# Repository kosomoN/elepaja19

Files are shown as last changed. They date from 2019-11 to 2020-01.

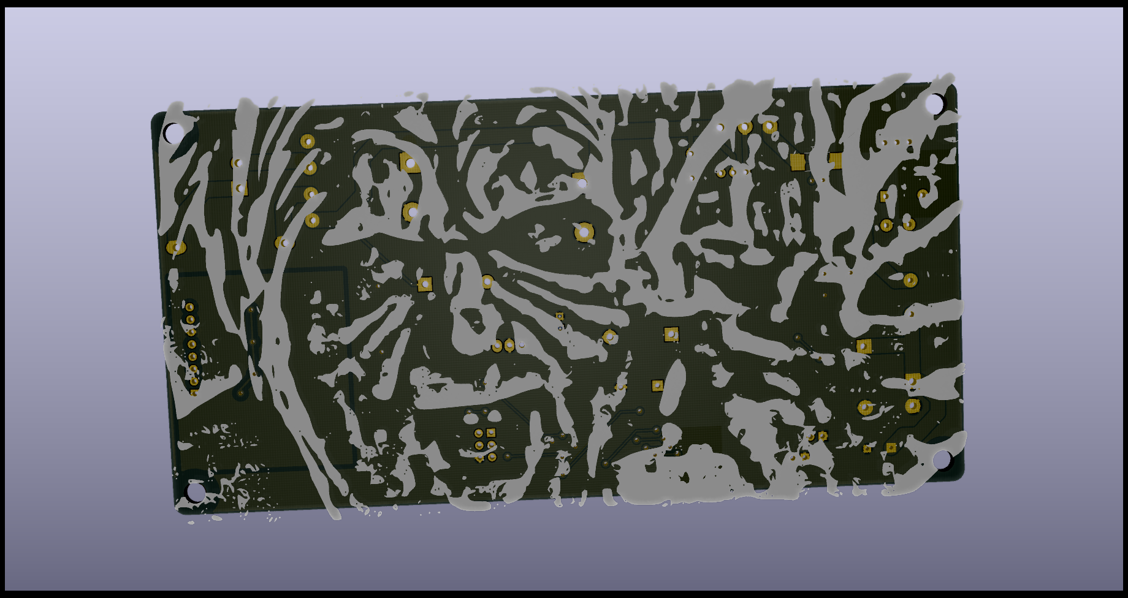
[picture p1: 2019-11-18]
pcb_1/pcb_1.png

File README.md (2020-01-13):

## Lab power supply

This repository contains firmware and PCB designs for a lab power supply designed by Onni Kosomaa, Jere Mielty and Juha Rauhala.

### Repository contents

| Folder | Contents |
| --- | --- |
| [components](components) | Custom KiCad component used in the schematics. |
| [control_mc](control_mc) | The regulator MCU firmware. |
| [pcb_1](pcb_1) | The main regulator PCB KiCad project. |
| [pcb_PiHat](pcb_PiHat) | The Raspberry Pi Zero extension PCB KiCad project. |
| [pcb_fpanel](pcb_fpanel) | The main front panel keyboard PCB. |
| [pcb_fpanel2](pcb_fpanel2) | The auxiliary front panel keyboard PCB. |
| [ui](ui) | UI software running on the Raspberry Pi. |

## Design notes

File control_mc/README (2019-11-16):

Dependencies:
    - avr-gcc and avr-libc
    - Atmel pack with ATMEGA328PB files. Looks for them by default in
     ../../packs/gcc/dev/atmega328pb/ and ../../packs/include/
     The pack can be found here: http://packs.download.atmel.com/
                                 (Atmel ATmega Series Device Support (1.4.331))

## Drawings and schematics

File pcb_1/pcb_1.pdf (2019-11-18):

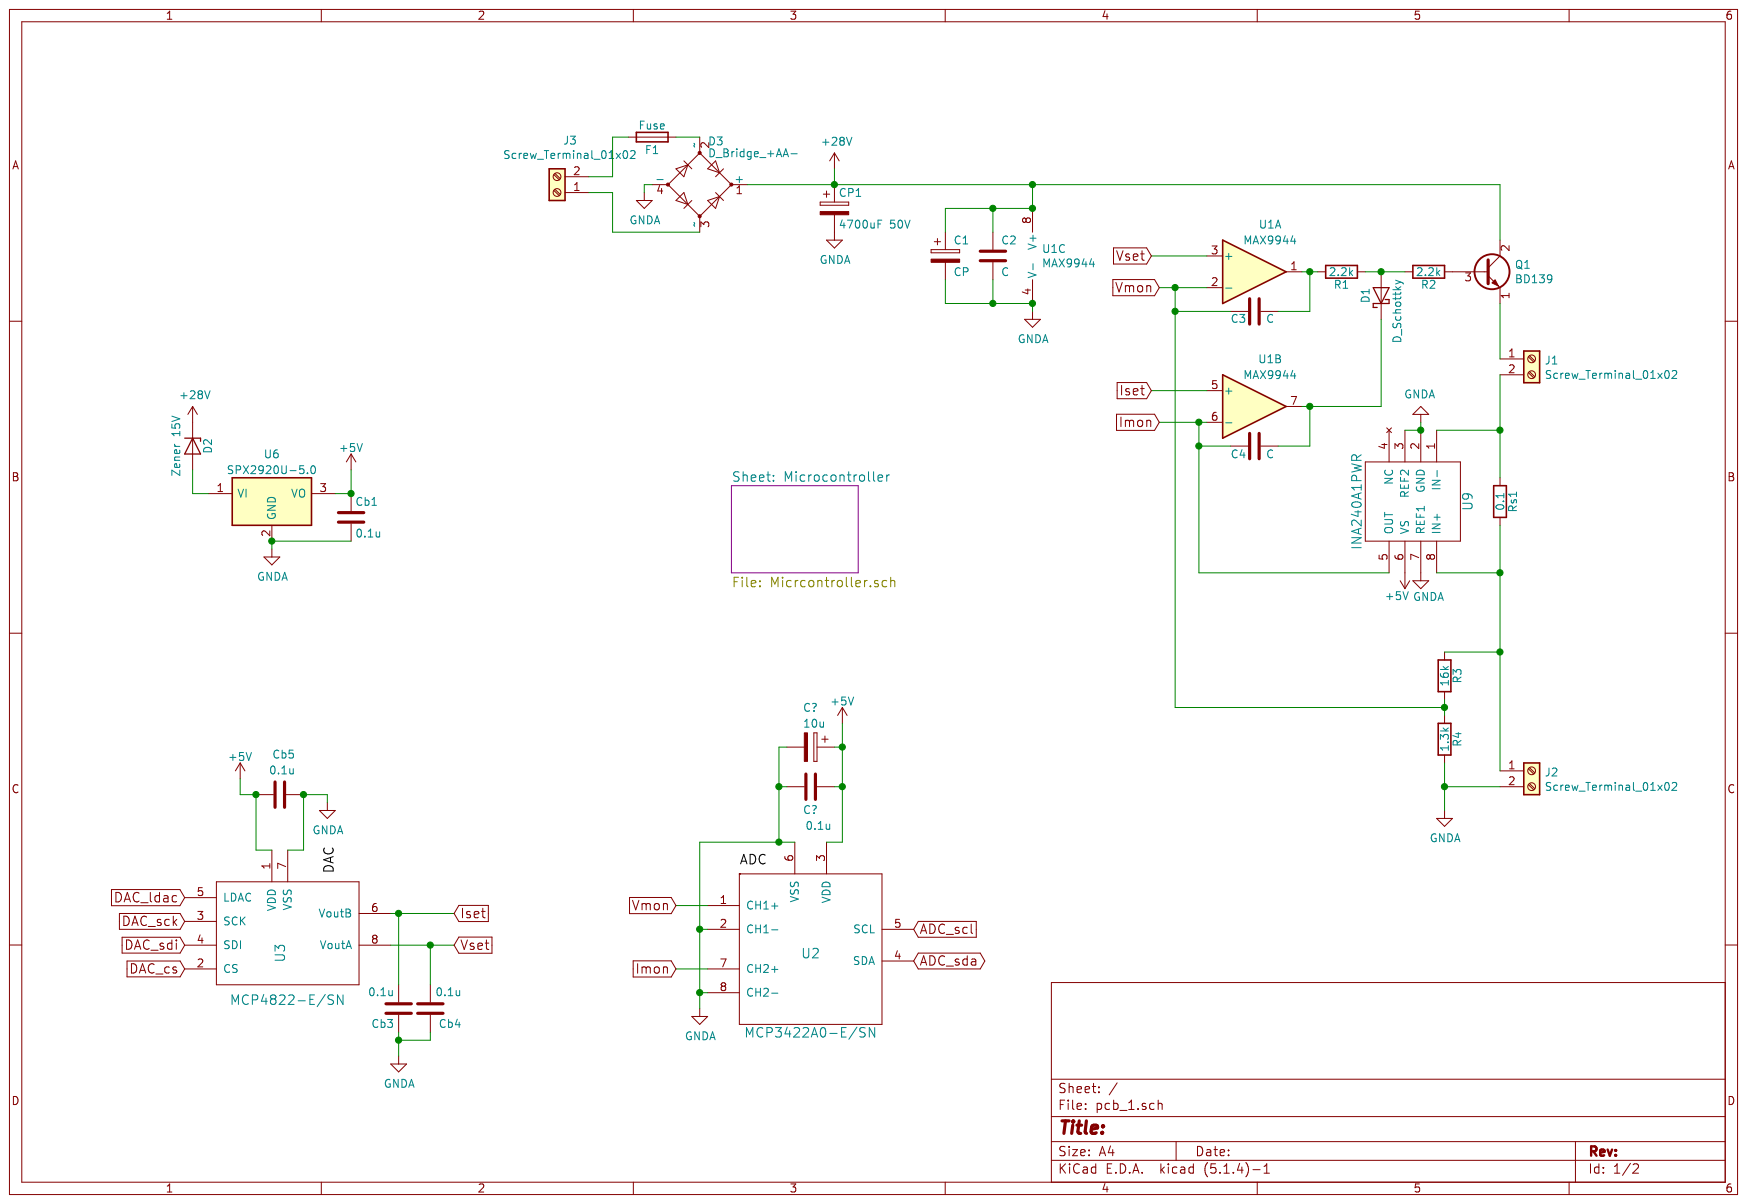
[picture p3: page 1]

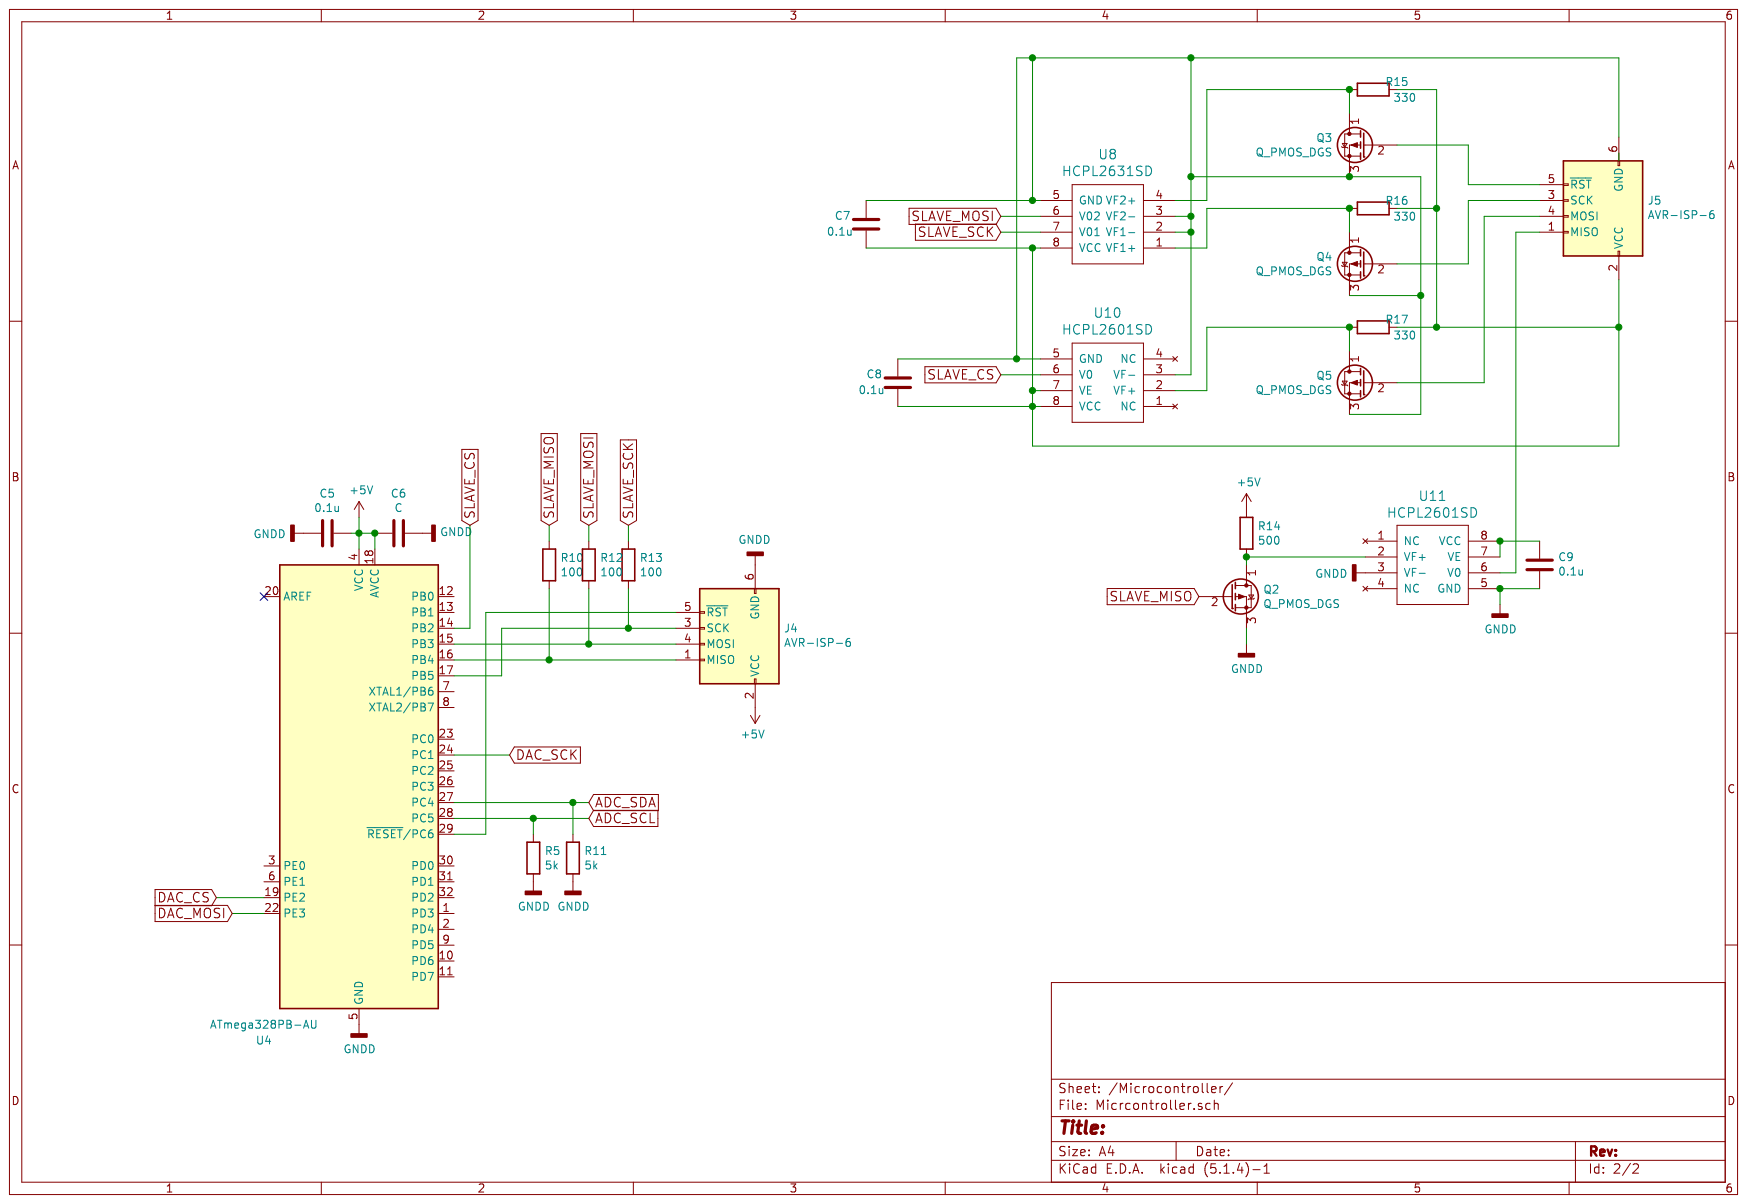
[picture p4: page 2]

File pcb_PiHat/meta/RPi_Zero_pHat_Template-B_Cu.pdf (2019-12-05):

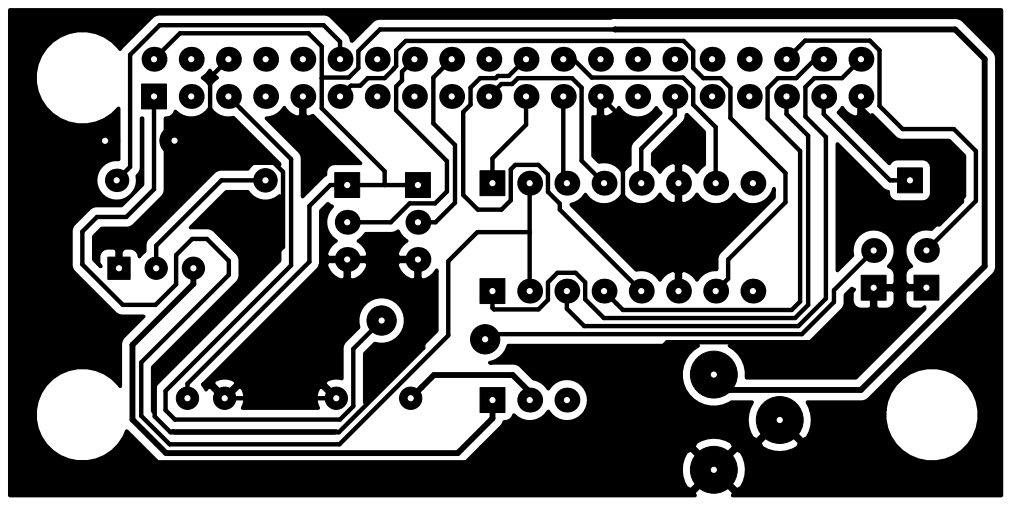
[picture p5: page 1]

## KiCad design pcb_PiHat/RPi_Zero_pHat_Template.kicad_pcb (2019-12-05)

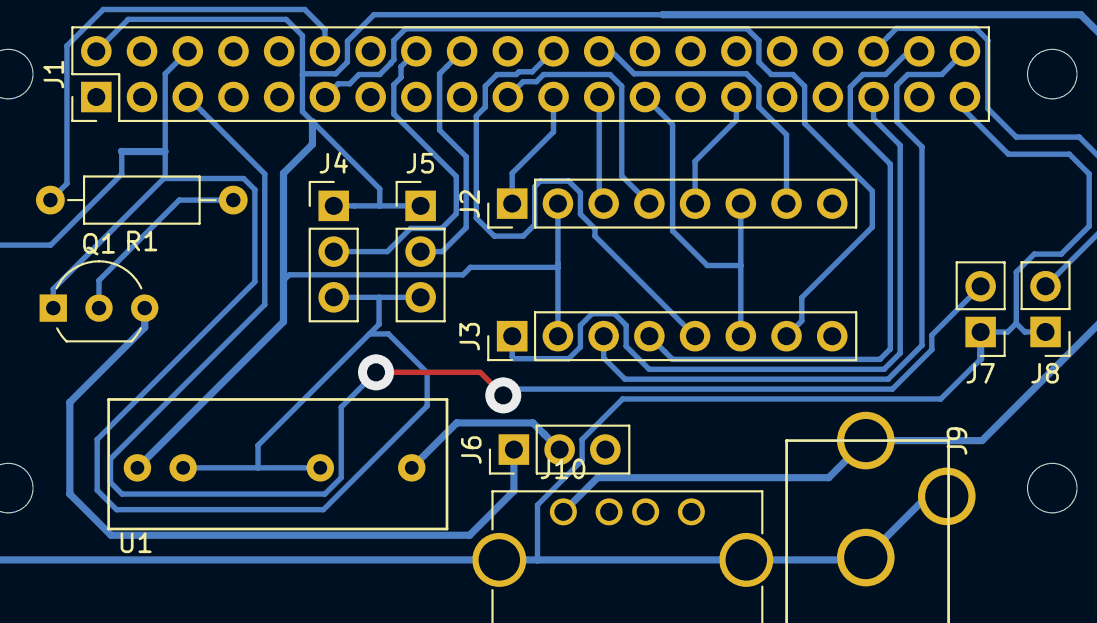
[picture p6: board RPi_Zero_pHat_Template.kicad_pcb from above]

Board: 2 copper layers, 13 parts (0 on the bottom side), 20 nets.

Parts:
J1: RPi_GPIO; PinHeader_2x20_P2.54mm_Vertical
J2, J3: Isolated_ISP; PinHeader_1x08_P2.54mm_Vertical
J4, J5: Conn_Relay; PinHeader_1x03_P2.54mm_Vertical
J6: Conn_01x03; Pin_Header_Straight_1x03_Pitch2.54mm
J7, J8: Conn_switch; Pin_Header_Straight_1x02_Pitch2.54mm
J9: 5V_in; 5V_power
J10: USB_A
Q1: Q_NPN_EBC; TO-92_Inline_Wide
R1: R; R_Axial_DIN0207_L6.3mm_D2.5mm_P10.16mm_Horizontal
U1: SPUN02L-12

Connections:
GND: J1.6, J1.9, J1.14, J1.20, J1.25, J1.30, J1.34, J1.39, J2.6, J3.6, J4.3, J5.3, J7.1, J8.1, J9.2, J10.4, J10.5, Q1.1, U1.2, U1.5
unnamed: J1.2, J2.2, J3.2, J4.1, J5.1, J9.1, J10.1, U1.1
unnamed: J1.5, J7.2
unnamed: J1.11, J3.7
unnamed: J1.12, R1.2
unnamed: J1.16, J4.2
unnamed: J1.18, J5.2
unnamed: J1.19, J2.4
unnamed: J1.21, J2.1
unnamed: J1.22, J3.5
unnamed: J1.23, J2.3
unnamed: J1.24, J2.7
unnamed: J1.29, J2.5
unnamed: J1.35, J3.1
unnamed: J1.36, J8.2
unnamed: J1.38, J3.4
unnamed: J1.40, J3.3
unnamed: J6.1, Q1.3
unnamed: J6.2, U1.7
unnamed: Q1.2, R1.1

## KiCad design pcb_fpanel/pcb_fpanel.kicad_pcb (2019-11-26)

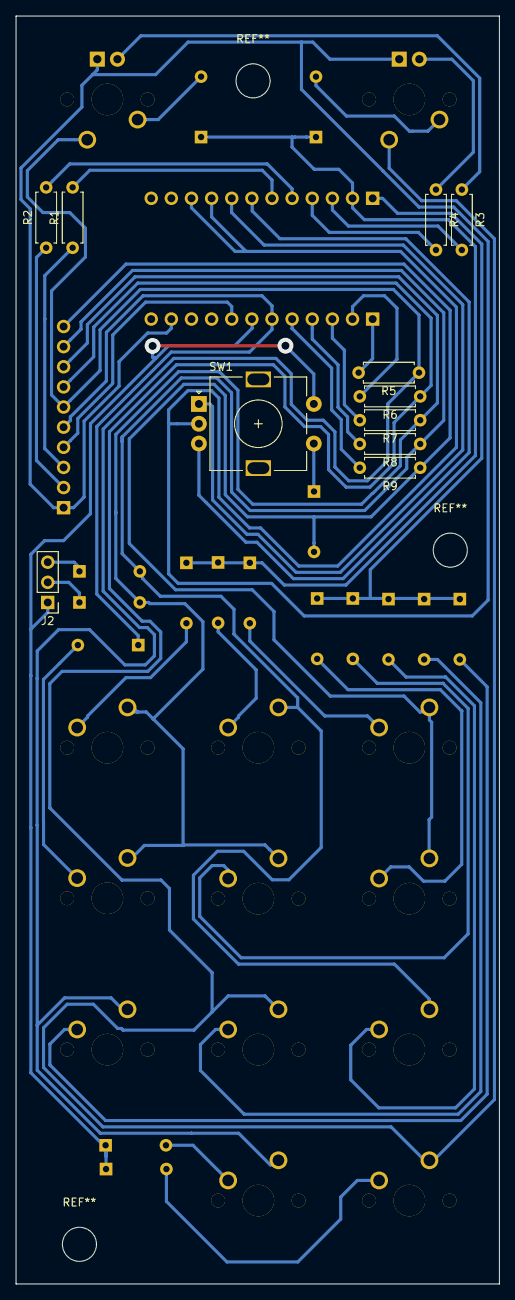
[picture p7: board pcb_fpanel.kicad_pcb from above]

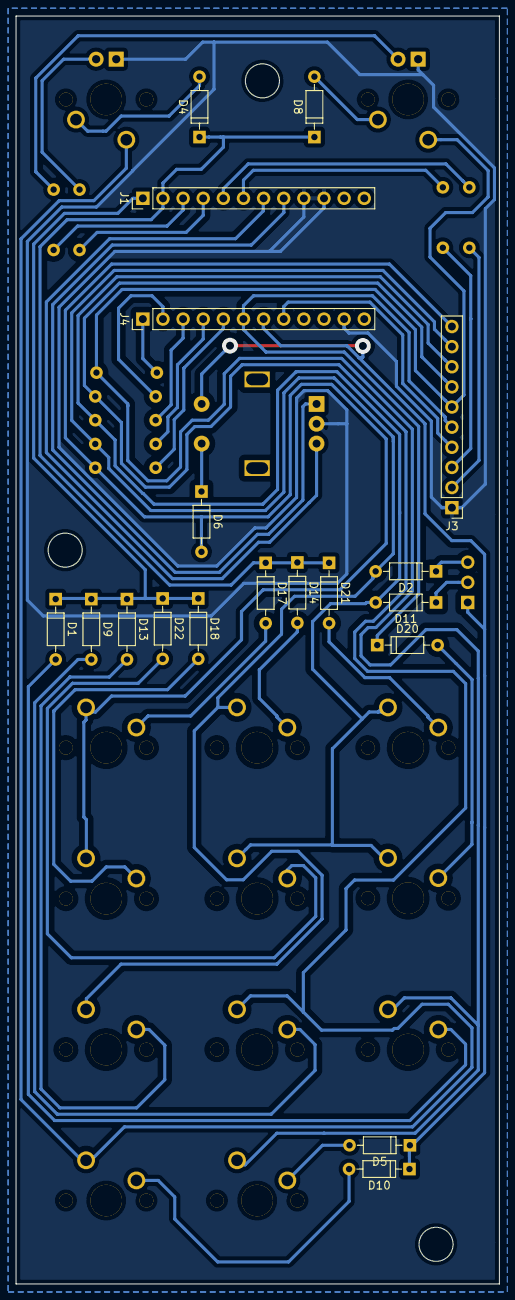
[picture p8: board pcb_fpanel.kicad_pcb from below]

Board: 2 copper layers, 61.0 x 160.0 mm, 43 parts (19 on the bottom side), 40 nets.

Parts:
D1, D2, D4, D5, D6, D8, D9, D10, D11, D13, D14, D17, D18, D20, D21, D22: D; D_DO-35_SOD27_P7.62mm_Horizontal
J1, J4: Conn_01x12; Pin_Header_Straight_1x12_Pitch2.54mm
J2: Conn_01x03; Pin_Header_Straight_1x03_Pitch2.54mm
J3: Conn_01x10; Pin_Header_Straight_1x10_Pitch2.54mm
R1, R2, R3, R4, R5, R6, R7, R8, R9: R; R_Axial_DIN0207_L6.3mm_D2.5mm_P7.62mm_Horizontal
SW1: Rotary_Encoder_Switch; RotaryEncoder_Alps_EC11E-Switch_Vertical_H20mm
SW3, SW8: SW_Push_LED; MXOnly-1U
SW4, SW5, SW9, SW10, SW13, SW14, SW17, SW18, SW20, SW21, SW22: SW_Push_LED; MXOnly-1U-NoLED

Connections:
GNDD: J1.9, J1.10, J3.1, J4.11, SW1.C
unnamed: D1.2, SW4.1
unnamed: D2.1, J2.3
unnamed: D4.2, SW3.1
unnamed: D5.2, SW5.1
unnamed: D8.2, SW8.1
unnamed: D9.2, SW9.1
unnamed: D10.2, SW10.1
unnamed: D11.1, J2.2
unnamed: D13.2, SW14.1
unnamed: D14.2, SW13.1
unnamed: D17.2, SW17.1
unnamed: D18.2, SW18.1
unnamed: D20.2, SW20.1
unnamed: D21.2, SW21.1
unnamed: D22.2, SW22.1
unnamed: J1.3, R3.2
unnamed: J1.4, R4.2
unnamed: J1.5, R2.2
unnamed: J1.6, R1.2
unnamed: J1.7, SW1.B
unnamed: J1.8, SW1.A
unnamed: J4.1, R5.2
unnamed: J4.2, R6.2
unnamed: J4.3, R7.2
unnamed: J4.4, R8.2
unnamed: J4.5, R9.2
column_1: J3.6, R5.1, SW4.2, SW5.2, SW8.2
column_2: J3.7, R6.1, SW3.2, SW9.2, SW10.2
column_3: D2.2, J3.9, R8.1, SW13.2, SW14.2
column_4: D6.2, J3.10, R9.1, SW17.2, SW18.2
column_5: D11.2, J3.8, R7.1, SW20.2, SW21.2, SW22.2
encoder_button: D6.1, SW1.S1
led_1: J3.3, R1.1
led_2: J3.2, R2.1
row_1: J3.4, J4.8
row_2: D20.1, J3.5, J4.6
row_3: D4.1, D8.1, D14.1, D17.1, D21.1, J1.2
row_4: D1.1, D9.1, D13.1, D18.1, D22.1, J1.1
row_5: D5.1, D10.1, J2.1, J4.7, SW1.S2

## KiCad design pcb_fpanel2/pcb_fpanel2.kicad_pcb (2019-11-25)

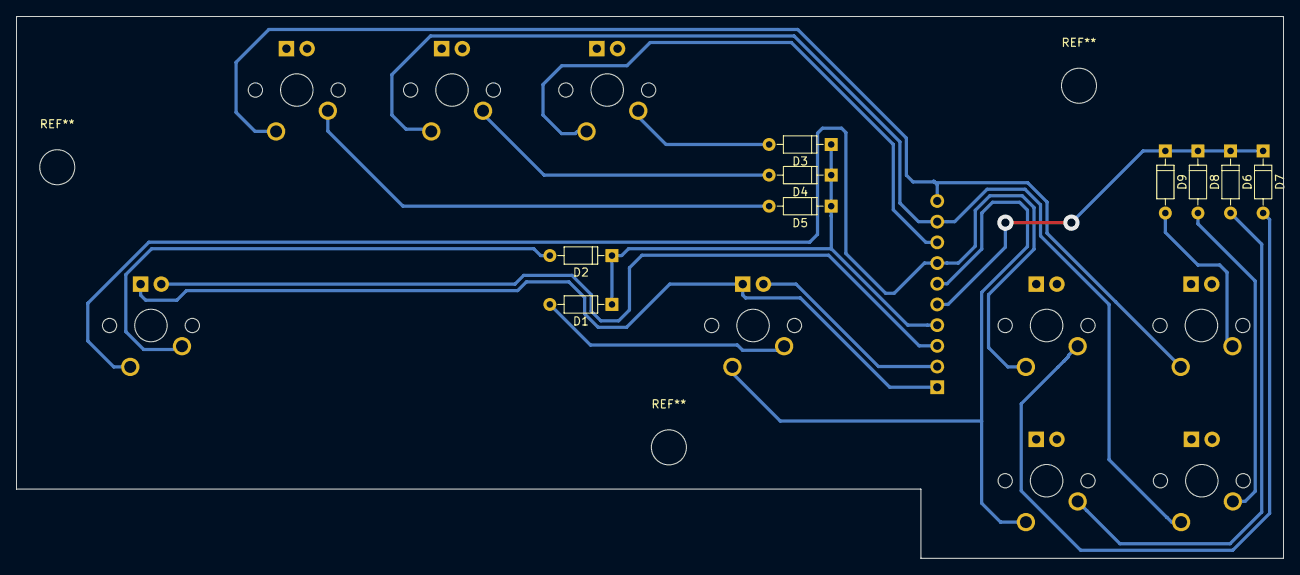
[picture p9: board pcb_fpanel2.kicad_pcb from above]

Board: 2 copper layers, 155.5 x 66.5 mm, 19 parts (1 on the bottom side), 19 nets.

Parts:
D1, D2, D3, D4, D5, D6, D7, D8, D9: D; D_DO-35_SOD27_P7.62mm_Horizontal
J1: Conn_01x10; Pin_Header_Straight_1x10_Pitch2.54mm
SW1, SW2, SW3, SW4, SW5, SW6, SW7, SW8, SW9: SW_Push_LED; MXOnly-1U

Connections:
GNDD: J1.1, SW1.4, SW2.4
unnamed: D1.2, SW1.1
unnamed: D2.2, SW2.1
unnamed: D3.2, SW3.1
unnamed: D4.2, SW4.1
unnamed: D5.2, SW5.1
unnamed: D6.2, SW6.1
unnamed: D7.2, SW7.1
unnamed: D8.2, SW8.1
unnamed: D9.2, SW9.1
column_1: J1.6, SW1.2, SW6.2
column_2: J1.7, SW2.2, SW7.2
column_3: J1.9, SW4.2, SW8.2
column_4: J1.10, SW5.2, SW9.2
column_5: J1.8, SW3.2
led_1: J1.3, SW2.3
led_2: J1.2, SW1.3
row_1: D1.1, D2.1, D3.1, D4.1, D5.1, J1.4
row_2: D6.1, D7.1, D8.1, D9.1, J1.5

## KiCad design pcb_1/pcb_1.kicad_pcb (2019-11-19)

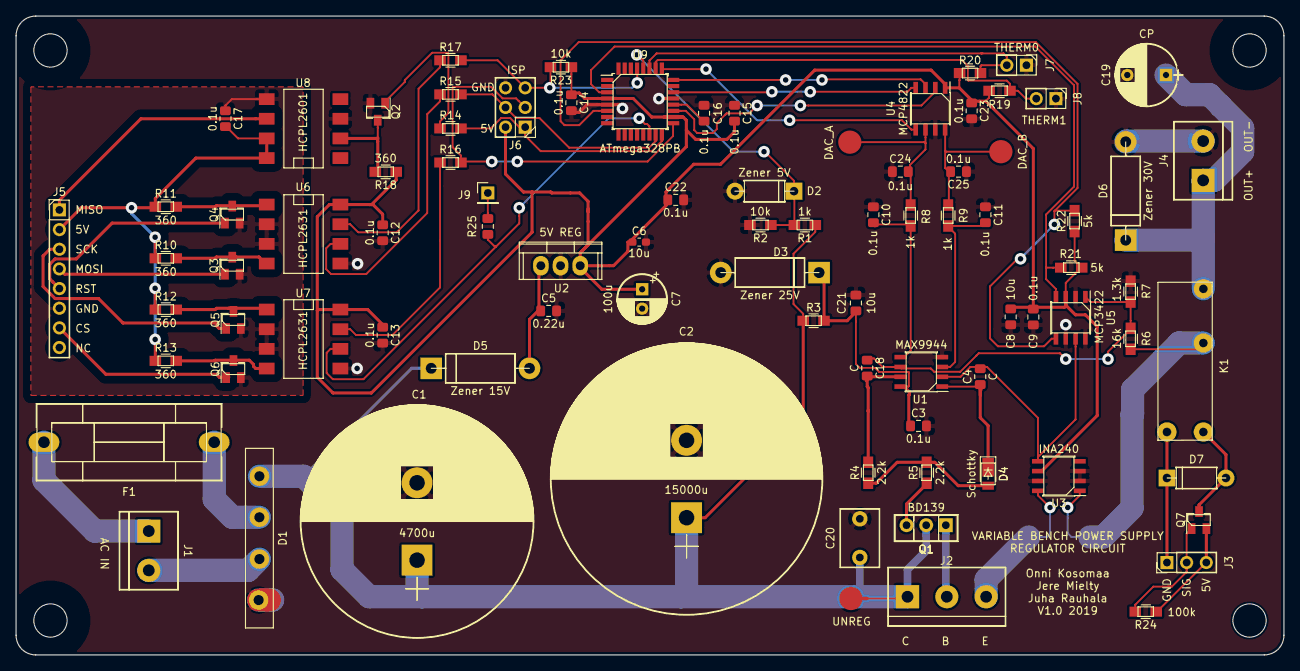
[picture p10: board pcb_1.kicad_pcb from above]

Board: 2 copper layers, 163.8 x 82.6 mm, 88 parts (1 on the bottom side), 58 nets.

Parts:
C1: 4700u; CP_Radial_D30.0mm_P10.00mm_SnapIn
C2: 15000u; CP_Radial_D35.0mm_P10.00mm_SnapIn
C3, C9, C10, C11, C12, C13, C14, C15, C16, C17, C22, C23, C24, C25: 0.1u; C_0805_2012Metric_Pad1.15x1.40mm_HandSolder
C4, C18: C; C_0805_2012Metric_Pad1.15x1.40mm_HandSolder
C5: 0.22u; C_0805_2012Metric_Pad1.15x1.40mm_HandSolder
C6: 10u; C_0603_1608Metric_Pad1.05x0.95mm_HandSolder
C7: 100u; CP_Radial_D6.3mm_P2.50mm
C8, C21: 10u; C_0805_2012Metric_Pad1.15x1.40mm_HandSolder
C19: CP; CP_Radial_D8.0mm_P5.00mm
C20: C; C_Disc_D7.5mm_W5.0mm_P5.00mm
D1: D_Bridge_+AA-; GBU6D_diode-bridge
D2: Zener 5V; D_DO-41_SOD81_P7.62mm_Horizontal
D3: Zener 25V; D_5W_P12.70mm_Horizontal
D4: Schottky; D_PowerDI-123
D5: Zener 15V; D_5W_P12.70mm_Horizontal
D6: Zener 30V; D_5W_P12.70mm_Horizontal
D7: D; D_DO-41_SOD81_P7.62mm_Horizontal
F1: Fuse; Fuseholder5x20_horiz_SemiClosed_Casing10x25mm
J1, J4: Screw_Terminal_01x02; TerminalBlock_bornier-2_P5.08mm
J2: Screw_Terminal_01x03; TerminalBlock_bornier-3_P5.08mm
J3: Conn_Relay; Pin_Header_Straight_1x03_Pitch2.54mm
J5: Isolated_ISP; Pin_Header_Straight_1x08_Pitch2.54mm
J6: AVR-ISP-6; Pin_Header_Straight_2x03_Pitch2.54mm
J7: THERM0; Pin_Header_Straight_1x02_Pitch2.54mm
J8: THERM1; Pin_Header_Straight_1x02_Pitch2.54mm
J9: CS; PinHeader_1x01_P2.54mm_Vertical
K1: DIPxx-1Axx-11x; PCJ-105D3MH
Q1: BD139; TO-126_Vertical
Q2, Q3, Q4, Q5, Q6, Q7: Q_NMOS_GSD; SuperSOT-3
R1, R8, R9: 1k; R_0805_HandSoldering
R2, R23: 10k; R_0805_HandSoldering
R3, R19, R20: R; R_0805_HandSoldering
R4, R5: 2.2k; R_0805_HandSoldering
R6: 16k; R_0805_HandSoldering
R7: 1.3k; R_0805_HandSoldering
R10, R11, R12, R13, R18: 360; R_0805_HandSoldering
R14, R15, R16, R17: 100; R_0805_HandSoldering
R21, R22: 5k; R_0805_HandSoldering
R24: 100k; R_0805_HandSoldering
R25: 100; R_0805_2012Metric_Pad1.15x1.40mm_HandSolder
Rs1: 0.1; R_2512_HandSoldering
TP1: UNREG; Measurement_Point_Round-SMD-Pad_Big
TP2: DACa; Measurement_Point_Round-SMD-Pad_Big
TP3: DACb; Measurement_Point_Round-SMD-Pad_Big
U1: MAX9944; SOIC-8_3.9x4.9mm_Pitch1.27mm
U2: 5V REG; TO-220
U3: INA240; SOIC-8_3.9x4.9mm_Pitch1.27mm
U4: MCP4822; SOIC-8_3.9x4.9mm_Pitch1.27mm
U5: MCP3422; SOIC-8_3.9x4.9mm_Pitch1.27mm
U6, U7: HCPL2631; HCPL2631SD
U8: HCPL2601; HCPL2631SD
U9: ATmega328PB; TQFP-32_7x7mm_Pitch0.8mm

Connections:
+5V: C6.1, C7.1, C8.1, C9.2, C12.1, C13.1, C14.1, C15.2, C22.1, C23.1, J6.2, R18.1, R19.1, R20.1, R21.1, R22.1, R23.1, U2.3, U3.6, U4.1, U5.3, U6.8, U7.8, U9.4, U9.18
ADC_SCL: R22.2, U5.5, U9.6
ADC_SDA: R21.2, U5.4, U9.3
DAC_CS: U4.2, U9.19
DAC_LDAC: U4.5, U9.25
DAC_SCK: U4.3, U9.24
DAC_SDI: U4.4, U9.22
GNDA: C1.2, C2.2, C3.2, C5.2, C6.2, C7.2, C8.2, C9.1, C10.1, C11.1, C12.2, C13.2, C14.2, C15.1, C16.2, C19.2, C20.2, C21.2, C22.2, C23.2, C24.1, C25.1, D1.4, D2.2, D3.2, D6.2, J4.2, J6.6, J7.1, J8.1, Q2.2, R2.2, R7.2, U1.4, U2.2, U3.2, U3.3, U3.7, U4.7, U5.2, U5.6, U5.8, U6.5, U7.5, U8.3, U9.5, U9.21
Imon: C4.2, U1.2, U3.5, U5.7
Iset: C11.2, R9.1, U1.3
unnamed: C1.1, C2.1, C20.1, D1.1, D5.1, J2.1, Q1.2, R1.1, R3.1, TP1.1
unnamed: C4.1, D4.1, U1.1
unnamed: C5.1, D5.2, U2.1
unnamed: C16.1, U9.20
unnamed: C17.1, J5.6, Q3.2, Q4.2, Q5.2, Q6.2, U6.2, U6.3, U7.2, U7.3, U8.5
unnamed: C17.2, J5.2, R10.1, R11.1, R12.1, R13.1, U8.7, U8.8
unnamed: C18.2, R4.2, U1.7
unnamed: C19.1, D6.1, J4.1, K1.7
unnamed: C3.1, C21.1, D3.1, R3.2, U1.8
unnamed: C24.2, R8.2, TP2.1, U4.6
unnamed: C25.2, R9.2, TP3.1, U4.8
unnamed: D1.2, F1.1
unnamed: D1.3, J1.2
unnamed: D4.2, R4.1, R5.2
unnamed: D7.1, J3.1, K1.2
unnamed: D7.2, K1.6, Q7.3
unnamed: F1.2, J1.1
unnamed: J2.2, Q1.1
unnamed: J2.3, Rs1.1, U3.8
unnamed: J3.2, Q7.1, R24.2
unnamed: J3.3, Q7.2, R24.1
unnamed: J5.1, U8.6
unnamed: J5.3, Q5.1
unnamed: J5.4, Q3.1
unnamed: J5.5, Q4.1
unnamed: J5.7, Q6.1
unnamed: J6.1, R14.2, U9.16
unnamed: J6.3, R16.2, U9.17
unnamed: J6.4, R15.2, U9.15
unnamed: J6.5, R17.2, R23.2, U9.29
unnamed: J7.2, R20.2, U9.27
unnamed: J8.2, R19.2, U9.26
unnamed: J9.1, R25.1
unnamed: K1.1, R6.1, Rs1.2, U3.1
unnamed: Q1.3, R5.1
unnamed: Q2.3, R18.2, U8.2
unnamed: Q3.3, R10.2, U6.4
unnamed: Q4.3, R11.2, U6.1
unnamed: Q5.3, R12.2, U7.1
unnamed: Q6.3, R13.2, U7.4
SLAVE_CS: R25.2, U7.6, U9.14
SLAVE_MISO: Q2.1, R14.1
SLAVE_MOSI: R15.1, U6.6
SLAVE_RESET: R17.1, U6.7
SLAVE_SCK: R16.1, U7.7
UNREG_MON: D2.1, R1.2, R2.1, U9.28
Vmon: C18.1, R6.2, R7.1, U1.6, U5.1
Vset: C10.2, R8.1, U1.5

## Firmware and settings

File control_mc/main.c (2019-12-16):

#include "constants.h"
#include "spi_protocol.h"

#include "avr-i2c/i2c.h"
#include <avr/cpufunc.h>
#include <avr/interrupt.h>
#include <avr/wdt.h>
#include <util/delay.h>

#include <stdbool.h>
#include <string.h>

#define SPI_BUFFER_SIZE 5

uint8_t spi_rx_buffer[SPI_BUFFER_SIZE] = { 0 };
uint8_t spi_tx_buffer[SPI_BUFFER_SIZE] = { 0 };
uint8_t spi_buf_length = 0;
bool spi_packet_ready = false;

struct {
    uint16_t voltage;
    uint16_t current;
} typedef OutputValues;

// Always disable interrupts when accessing.
static OutputValues set_values;
static OutputValues read_values;

/*
 * State of the ADC communication.
 * Every ADC conversion first requires an I2C write operation to select the
 * correct channel. After the write, the ADC needs sufficient time to finish
 * the conversion before an I2C read operation can be made.
 *
 * ADC_RD/WR: I2C read/write operation in progress.
 * ADC_WTNG: Conversion in progress, I2C bus is idling.
 * ADC_UNINIT: State at start. Will initiate a voltage conversion.
 */
enum {
    ADC_WR_VOLTAGE,
    ADC_WTNG_VOLTAGE,
    ADC_RD_VOLTAGE,
    ADC_WR_CURRENT,
    ADC_WTNG_CURRENT,
    ADC_RD_CURRENT,
    ADC_UNINIT
} adc_state;

i2c_txn_t i2c_t;
uint8_t i2c_buf[4];

ISR(SPI0_STC_vect)
{
    if (spi_buf_length < SPI_BUFFER_SIZE)
    {
        spi_rx_buffer[spi_buf_length] = SPDR0;
        SPDR0 = spi_tx_buffer[spi_buf_length];
        spi_buf_length++;
    }
}

// Use an interrupt on the slave SPI chip select pin
// to reset the SPI rx/tx buffers.
ISR(PCINT0_vect)
{
    // Falling edge means start of SPI transfer
    if (PIN_SS0 & (1 << PIN_SS0_PIN)) {
        spi_packet_ready = true;
    } else {
        spi_packet_ready = false;
        spi_buf_length = 0;
        spi_tx_buffer[0] = read_values.voltage >> 8;
        spi_tx_buffer[1] = read_values.voltage;
        spi_tx_buffer[2] = read_values.current >> 8;
        spi_tx_buffer[3] = read_values.current;
    }
}

// SPI interrupt executed after a byte has been received.
static void setupSlaveSPI(void)
{
    // Set data direction
    DDR_MISO0 |= 1 << DD_MISO0;

    // Enable pull-ups as the optocouplers are open-collector
    PORT_SPI0 |= (1 << PORT_MOSI0_PIN) |
                 (1 << PORT_SCK0_PIN)  |
                 (1 << PORT_SS0_PIN);

    // Enable pin-change interrupt on chip select pin
    PCICR |= (1 << PCIE0); // Enable pin change interrupt 1
    PCMSK0 |= (1 << PCINT2); // Enable interrupt for pin 14 (chip select)

    // Enable SPI, with interrupt
    SPCR0 = (1 << SPE) |
            (1 << SPIE) |
            (MAIN_SPI_CPOL << CPOL) |
            (MAIN_SPI_CPHA << CPHA);
}

static void setupDAC(void)
{
    // Set data directions
    DDR_SCK1    |= 1 << DD_SCK1;
    DDR_MOSI1   |= 1 << DD_MOSI1;
    DDR_DAC_CS   |= 1 << DD_DAC_CS;
    DDR_DAC_LDAC |= 1 << DD_DAC_LDAC;

    // Enable SPI, master mode, no interrupt
    SPCR1 = (1 << SPE1) | (1 << MSTR1) | DAC_CLOCK_RATE;
    // Lift chip select
    PORT_DAC_CS |= 1 << PORT_DAC_CS_PIN;
}

#ifdef ENABLE_ADC
static void setupADC(void)
{
    adc_state = ADC_UNINIT;
    i2c_txn_init(&i2c_t, 1);

    // Initialize TIMER0 for conversion delaying
    TCCR0B = _BV(2) | _BV(0); // 1024 clock prescaler
    // Set compare value to (delay / timer0_period)
    const uint8_t compare_val = ADC_CONV_DELAY_US / (1024U * 1000000U / F_CPU);
    OCR0A = compare_val;
}
#endif

// Writes the set values for current and voltage to the DAC.
// Blocks until complete.
// Data protocol: http://ww1.microchip.com/downloads/en/DeviceDoc/20002249B.pdf
static void writeDAC(OutputValues *values)
{
    // Make a local copy to avoid data races
    cli();
    OutputValues tmp_values = *values;
    sei();

    uint8_t bytes[4];

    uint8_t enable_volt = (tmp_values.voltage > 0) ? 1 : 0;
    uint8_t enable_curr = (tmp_values.current > 0) ? 1 : 0;

    bytes[0] = (1 << 7) |           // Channel A
               (1 << 5) |           // Gain 1x
               (enable_curr << 4) | // Enable ouput
               ((tmp_values.voltage >> 8) & 0x0F); // 4 MSBs.
    bytes[1] = tmp_values.voltage & 0xFF;

    bytes[2] = (0 << 7) |           // Channel B
               (1 << 5) |           // Gain 1x
               (enable_volt << 4) | // Enable ouput
               ((tmp_values.current >> 8) & 0x0F); // 4 MSBs.
    bytes[3] = tmp_values.current & 0xFF;


    // Write channel A
    PORT_DAC_CS &= ~(1 << PORT_DAC_CS_PIN);
    {
        SPDR1 = bytes[0];
        // Wait until the byte is transferred.
        while (!(SPSR1 & (1 << SPIF1))) { };
        SPDR1 = bytes[1];
        while (!(SPSR1 & (1 << SPIF1))) { };
    }
    PORT_DAC_CS |= 1 << PORT_DAC_CS_PIN;

    // 1 CPU cycle is enough for minimum CS high time

    // Write channel B
    PORT_DAC_CS &= ~(1 << PORT_DAC_CS_PIN);
    {
        SPDR1 = bytes[2];
        while (!(SPSR1 & (1 << SPIF1))) { };
        SPDR1 = bytes[3];
        while (!(SPSR1 & (1 << SPIF1))) { };
    }
    PORT_DAC_CS |= 1 << PORT_DAC_CS_PIN;

    // Latch outputs, with some delay to match minimum timing
    _NOP();
    PORT_DAC_LDAC &= ~(1 << PORT_DAC_LDAC_PIN);
    _NOP();
    PORT_DAC_LDAC |= (1 << PORT_DAC_LDAC_PIN);
}

int main(void)
{
    // Enable watchdog. See https://microchipdeveloper.com/8avr:avrwdt
    // https://www.nongnu.org/avr-libc/user-manual/group__avr__watchdog.html
    wdt_enable(WDTO_4S);
    wdt_reset();

    DDRC |= 1 << DDC4;
    PORTC |= 1 << PORTC4;

    setupDAC();
#ifdef ENABLE_ADC
    setupADC();
#endif

    // Enable global interrupts
    sei();

    // Initialize DAC output to zero
    memset(&set_values, 0, sizeof(set_values));
    memset(&read_values, 0, sizeof(read_values));
    writeDAC(&set_values);

    setupSlaveSPI();
    while (true) {
        wdt_reset();

        if (spi_packet_ready) {
            uint8_t packet_type = 0;
            cli();
            {
                // Make sure the packet has not been cleared before
                // the cli instruction got executed.
                if (spi_packet_ready) {
                    spi_packet_ready = false;
                    packet_type = spi_rx_buffer[0];
                    if (packet_type == READWRITE && spi_buf_length == 5) {
                        set_values.voltage = ((spi_rx_buffer[1] & 0x0F) << 8) |
                                               spi_rx_buffer[2];
                        set_values.current = ((spi_rx_buffer[3] & 0x0F) << 8) |
                                               spi_rx_buffer[4];
                    }
                }
            }
            sei();

            // Enable interrupts before actually writing the values to DAC
            if (packet_type == READWRITE) {
                writeDAC(&set_values);

                PINC |= 1 << PINC4;
            }
        }

        switch (adc_state)
        {
        case ADC_UNINIT:
            // Initiate a new write
            i2c_buf[0] = ADC_VOLT_CONF;
            i2c_op_init_wr(&i2c_t.ops[0], ADC_ADDRESS, i2c_buf, 1);
            i2c_post(&i2c_t);
            adc_state = ADC_WR_VOLTAGE;
            break;
        case ADC_WR_VOLTAGE:
        case ADC_WR_CURRENT:
            if (i2c_t.flags & I2C_TXN_DONE)  {
                if (i2c_t.flags & I2C_TXN_ERR) {
                    // TODO Handle error
                    adc_state = ADC_UNINIT;
                } else {
                    TCNT0 = 0;          // Reset TIMER0
                    TIFR0 = _BV(OCF0A); // Reset Compare A
                    adc_state = (adc_state == ADC_WR_VOLTAGE) ? ADC_WTNG_VOLTAGE : ADC_WTNG_CURRENT;
                }
            }
            break;
        case ADC_WTNG_VOLTAGE:
        case ADC_WTNG_CURRENT:
            // Wait for TIMER0
            if (TIFR0 & _BV(OCF0A)) {
                i2c_op_init_rd(&i2c_t.ops[0], ADC_ADDRESS, i2c_buf, 3);
                i2c_post(&i2c_t);
                adc_state = (adc_state == ADC_WTNG_VOLTAGE) ? ADC_RD_VOLTAGE : ADC_RD_CURRENT;
            }
            break;
        case ADC_RD_VOLTAGE:
        case ADC_RD_CURRENT:
            if (i2c_t.flags & I2C_TXN_DONE) {
                if (i2c_t.flags & I2C_TXN_ERR) {
                    // TODO Handle error
                    adc_state = ADC_UNINIT;
                } else {
                    if (adc_state == ADC_RD_VOLTAGE) {
                        cli();
                        read_values.voltage = ((i2c_buf[0] & READ_HI_MASK) << 8) | i2c_buf[1];
                        sei();
                    } else {
                        cli();
                        read_values.current = ((i2c_buf[0] & READ_HI_MASK) << 8) | i2c_buf[1];
                        sei();
                    }

                    // Initiate a new write when reading is done
                    i2c_buf[0] = (adc_state == ADC_RD_VOLTAGE) ? ADC_CURR_CONF : ADC_VOLT_CONF;
                    i2c_op_init_wr(&i2c_t.ops[0], ADC_ADDRESS, i2c_buf, 1);
                    i2c_post(&i2c_t);

                    adc_state = (adc_state == ADC_RD_VOLTAGE) ? ADC_WR_CURRENT : ADC_WR_VOLTAGE;
                }
            }
            break;
        }
    }

    return 0;
}

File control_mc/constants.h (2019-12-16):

#ifndef CONSTANTS_H_
#define CONSTANTS_H_

#include <avr/io.h>

// DAC defines
// Clock rate: 1 / 128
#define DAC_CLOCK_RATE      ((1 << SPR0) | (1 << SPR1))

// Data direction registers
#define DDR_DAC_CS          DDRE
#define DD_DAC_CS           DDE2
#define DDR_DAC_LDAC        DDRC
#define DD_DAC_LDAC         DDC2

// Port registers (output high/low selection)
#define PORT_DAC_CS         PORTE
#define PORT_DAC_CS_PIN     PORTE2
#define PORT_DAC_LDAC       PORTC
#define PORT_DAC_LDAC_PIN   PORTC2

// ADC defines
// Just a plain divider
#define TWI_CLOCK_DIV       0xFF
#define ADC_ADDRESS         0x68
#define ADC_VOLT_CONF       (         _BV(4) | _BV(2))  // Channel 1, continuous, 14 bits
#define ADC_CURR_CONF       (_BV(5) | _BV(4) | _BV(2))  // Channel 2, continuous, 14 bits
#define ADC_CONV_FREQ       45                          // ~45 SPS at 14 bits
#define ADC_CONV_DELAY_US   (1000000U / ADC_CONV_FREQ)

// SPI pins
#define DDR_MISO0       DDRB
#define DD_MISO0        DDB4

#define PIN_SS0         PINB
#define PIN_SS0_PIN     PINB2

#define PORT_SPI0       PORTB
#define PORT_MOSI0_PIN  PORTB3
#define PORT_SCK0_PIN   PORTB5
#define PORT_SS0_PIN    PORTB2

#define DDR_MOSI1       DDRE
#define DD_MOSI1        DDE3
#define DDR_SCK1        DDRC
#define DD_SCK1         DDC1

#define DDR_SCL0        DDRC
#define DD_SCL0         DDC5
#define DDR_SDA0        DDRC
#define DD_SDA0         DDC4

#endif

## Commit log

2019-10-18 KiCad.gitignore lisätty
2019-10-18 KiCad projekti aloitettu
    [pcb_1.kicad_pcb, pcb_1.sch]
2019-10-19 Mittauspinnit lisätty
    [pcb_1.sch]
2019-10-19 AC-input lisätty Footprintit mikropiireille
    [_saved_pcb_1.sch, pcb_1.sch]
2019-10-19 -Tasasuuntaajalle footprint footprints kansiossa -Oparille lisätty kapasitpanssipaikkoja
    [_saved_pcb_1.sch, pcb_1.sch]
2019-10-20 pcb suunniteltu
    [pcb_1.kicad_pcb, pcb_1.sch]
2019-10-22 Oparin regu vaihdettu ja konkkien footprintejä muutettu
    [pcb_1.kicad_pcb, pcb_1.sch]
2019-10-22 UI Raylib pohja lisätty
    Lisää Makefile:in Raspberry PI:lle, Linuxille sekä Windowsille.
    Lisää myös Visual Studio 2017 projektin.
    Makefile sekä VS2017 etsii oletuksena Raylibiä
    elepaja19/../raylib kansiosta.
2019-10-24 Traceja paksunnettu
    [pcb_1.kicad_pcb, pcb_1.sch]
2019-10-28 INA240 kotelo vaihdettu ja toinen vastaava vahvistin poistettu
    [pcb_1.kicad_pcb, pcb_1.sch]
2019-10-29 Footprintteja muutettu oikeiksi
    [pcb_1.kicad_pcb]
2019-10-30 pcb:ssa nyt smd- ja tht-komponentit eri puolilla
    [pcb_1.kicad_pcb, pcb_1.sch]
2019-10-31 30.10 syövytetty pcb
    [pcb_1.kicad_pcb, pcb_1.sch]
2019-11-12 pcb: Add first version with a MCU
    Also update the Kicad project to Kicad version 5
    [Micrcontroller.sch, pcb_1.sch]
2019-11-13 pcb: Add relay and filtering capacitors
    [Micrcontroller.sch, pcb_1.sch]
2019-11-14 pcb: Fix mismatching global labels
    Also add connections for thermistors.
    [Micrcontroller.sch, pcb_1.sch]
2019-11-14 pcb: Add Zener regulator to op-amp supply
    [Micrcontroller.sch, pcb_1.sch]
2019-11-16 control_mc: Fix line endings in constants.h
    [constants.h]
2019-11-16 Footprintit asetettu ja pcb layout aloitettu
    [pcb_230.kicad_pcb, pcb_230.sch]
2019-11-16 Footprintit lisätty ja pcb-layout aloitettu
    [Micrcontroller.sch, pcb_1.kicad_pcb, pcb_1.sch]
2019-11-16 Komponentit aseteltu paikoilleen ja vähän traceja vedelty
    [pcb_1.kicad_pcb, pcb_1.sch]
2019-11-17 pcb: Releen ohjauspiiri lisätty
    [Micrcontroller.sch, pcb_1.kicad_pcb, pcb_1.sch]
2019-11-17 pcb: Kaikki vedot tehty
    [Micrcontroller.sch, pcb_1.kicad_pcb, pcb_1.sch]
2019-11-17 pcb_PiHat: Pi Hatin ensimmäinen versio lisätty
    [RPi_Zero_pHat_Template.kicad_pcb, RPi_Zero_pHat_Template.sch]
2019-11-17 pcb_PiHat: Relee headeri lisätty
    [RPi_Zero_pHat_Template.kicad_pcb, RPi_Zero_pHat_Template.sch]
2019-11-17 Toinen konkka lisätty
    [Micrcontroller.sch, pcb_1.kicad_pcb, pcb_1.sch]
2019-11-17 pcb: Rescue kirjasto poistettu
    [Micrcontroller.sch, pcb_1.kicad_pcb]
2019-11-17 pcb: Suodatuskonkat ja kiinnitysreiät lisätty
    [pcb_1.kicad_pcb, pcb_1.sch]
2019-11-17 pcb: Kulmat pyöristetty
    [pcb_1.kicad_pcb]
2019-11-18 NMOS-symbolit muutettu
    [Micrcontroller.sch, pcb_1.kicad_pcb, pcb_1.sch]
2019-11-18 pcb: Silkscreeniä päivitetty
    [Micrcontroller.sch, pcb_1.kicad_pcb, pcb_1.sch]
2019-11-18 pcb_PiHat: Toisen releen headeri lisätty
    [RPi_Zero_pHat_Template.kicad_pcb, RPi_Zero_pHat_Template.sch]
2019-11-18 pcb: Gerber tiedostot lisätty
    [Micrcontroller.sch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]
2019-11-18 pcb: Kondensaattoreiden footprintit muuttettu
    [Micrcontroller.sch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]
2019-11-19 pcb: Optcouplereitten virranrajotinvastkset muutettu
    [Micrcontroller.sch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]
2019-11-20 frontpanel pcb aloitettu
    [pcb_fpanel.kicad_pcb, pcb_fpanel.sch, pcb_fpanel2.kicad_pcb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]
2019-11-23 Frontpanel pcb valmis
    [pcb_fpanel.kicad_pcb, pcb_fpanel.sch, pcb_fpanel2.kicad_pcb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]
2019-11-24 Frontpanel pcb korjaus: led-napit käännetty ja yhteensopivuus arduino pro micron kanssa
    [pcb_fpanel.kicad_pcb, pcb_fpanel.sch, pcb_fpanel2.kicad_pcb]
2019-11-24 Interrupt pinnit muutettu PC->Ext
    [pcb_fpanel.kicad_pcb, pcb_fpanel.sch]
2019-11-24 fpanel1 ja fpanel2 välisen liittimen pin-järjestys korjattu vastaamaan toisiaan
    [pcb_fpanel2.kicad_pcb, pcb_fpanel2.sch]
2019-11-25 Näppäinmatriisin srakkeille lisätty etuvastukset
    [pcb_fpanel.kicad_pcb, pcb_fpanel.sch, pcb_fpanel2.kicad_pcb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]
2019-11-25 Reikien siirtelyä
    [pcb_fpanel.kicad_pcb, pcb_fpanel.sch, pcb_fpanel2.kicad_pcb]
2019-11-25 Näppäinten sijainnit ja footprintit päivitetty
    [pcb_fpanel.kicad_pcb, pcb_fpanel.sch, pcb_fpanel2.kicad_pcb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]
2019-11-25 pcb_fpanel2: Tekijät-teksti lisätty footprinttinä
2019-11-26 pcb_fpanel: Käyttämättömät footprint kirjastot poistettu
2019-11-26 pcb_fpanel: Käyttämättömien ledien reiät poistettu
    [pcb_fpanel.kicad_pcb]
2019-11-26 pcb_fpanel: Kytkimien footprintien reikätyyppejä muutettu
    [pcb_fpanel.kicad_pcb]
2019-12-01 control_mc: Add AVR fuse Makefile target
2019-12-01 control_mc: Add slave SPI protocol
2019-12-01 ui: Add SPI interface through wiringPi
2019-12-02 Merge branch 'master' of https://github.com/kosomoN/elepaja19.git
    # Conflicts:
    # pcb_fpanel/pcb_fpanel.kicad_pcb
2019-12-05 raspi hat toteutettu versio
    [RPi_Zero_pHat_Template.kicad_pcb, RPi_Zero_pHat_Template.sch]
2019-12-12 control_mc: Fix SPI packet processing and add avr-i2c
    [constants.h, i2c.c, main.c]
2019-12-14 pcbs: Remove unnecessary files
    [pcb_230.kicad_pcb, pcb_230.sch]
2019-12-16 control_mc: Finalize ADC reading
2019-12-28 ui: Add crude two-point calibration UI
